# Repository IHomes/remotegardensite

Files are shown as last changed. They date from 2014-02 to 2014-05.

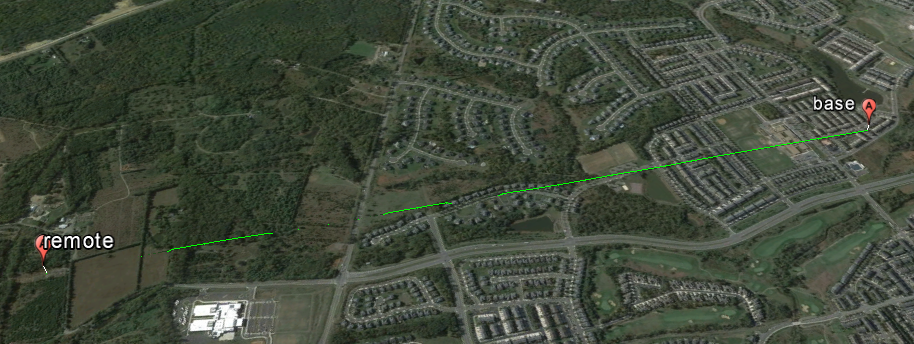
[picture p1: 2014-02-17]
rf_modeling/splat/example_misc_summary_files/Base_to_Remote_LineofSight.png

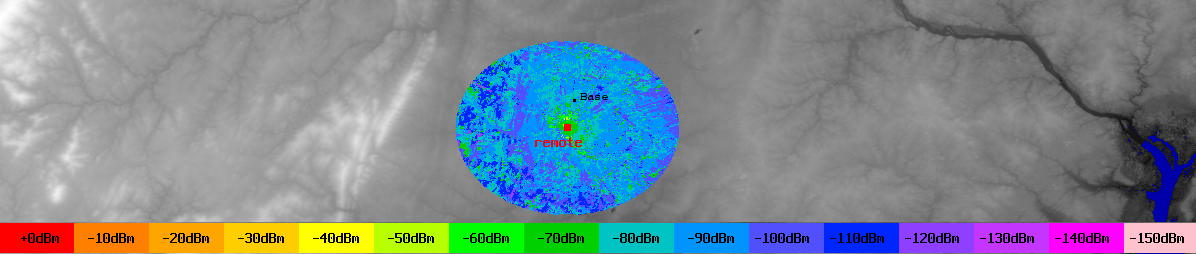
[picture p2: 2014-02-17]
rf_modeling/splat/example_misc_summary_files/Remote_xdBGain_coverage_dBm.png

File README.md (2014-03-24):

# Overview

A garden monitor/weather station hosted on a Raspberry Pi. This projects goal is to monitor the remote weather station over a great distance (miles,) and post the data online.

RPi Setup Reference:
RPi_remote_garden_monitor_prep_ArchLinux.txt

RPi900 Setup Reference:
rpi900_dnt900_setup_with_ppp.txt (Summary steps, see http://rpi900.com/ for full details)

##garden_monitor
Scripts to gather weather or hardware health data and post to xively

## public_html
Example html for displaying data.
-Historical displays powered by https://github.com/jasonneylon/xively-rickshaw

## sensors
Sensors and supporting scripts used in the remote garden monitor

##transeiver_dnt900
Data concerning a long distance communication transeiver utilized in this project

##rf_modeling
Sample data from RF communication modeling done for the base/remote setup.

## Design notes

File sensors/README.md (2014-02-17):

# Sensors used in the projects
-Air Temp Sensor (DS1820)
-Ground Temp Sensor (SHT10)
-Soil Moisture Sensor (SHT10)
-Pi Onboard CPU Temp (onboard/vcgencmd)
-Pi Camera (camera/raspistill)

## DS18B20
An i2c Digital temperature sensor (I happened to use adafruit Waterproof DS18B20 Digital temperature sensor + extras) for this project.

Each has a unique address, found with steps below. Script would need updating if you have more than of this type of sensor, reflecting the specific serial number perhaps

```
sudo modprobe w1-gpio
sudo modprobe w1-therm
cd /sys/bus/w1/devices
ls
cd 28-* #unique serial number for device, if you add multiple make sure to keep track of them
cat w1_slave  #indicates if temp can be provided in first line, temp in second.
```

Python script in this repo (thermometer.py) from this tutorial: 
http://learn.adafruit.com/adafruits-raspberry-pi-lesson-11-ds18b20-temperature-sensing

To run program:
```
cd DS18B20
python thermometer.py
```

## SH10
An i2c Soil/Moisture (humidity) sensor (again, I happened to use adafruit offering)

No-unique address, multiple *may* be possible with unique data lines

Followed this exactly:
http://www.john.geek.nz/2012/08/reading-data-from-a-sensirion-sht1x-with-a-raspberry-pi/

Requires BCM2835 library (included as-used in this repo, but latest: http://www.open.com.au/mikem/bcm2835 )

If used version of BCM2835 from this repo:

```
cd ./SHT10/support_files/bcm2835-1.36
./configure
make
sudo make check
sudo make install
```

To build program 

```
cd ../.. #SHT10
gcc -o RPi_SHT1x ./support_files/bcm2835-1.36/src/bcm2835.c ./RPi_SHT1x.c testSHT1x.c
```

To run program:

```
cd SHT10
./RPi_SHT1x
```
## Raspberry Pi Onboard Sensors

Ref: http://elinux.org/RPI_vcgencmd_usage

To list CPU core temp:

```
/opt/vc/bin/vcgencmd measure_temp
# or
gawk '{print $1/1000,"degrees C"}' /sys/class/thermal/thermal_zone0/temp
```

## Pi Camera

Script to grab an image every 30 seconds, Ref: http://www.stuffaboutcode.com/2013/05/time-lapse-video-with-raspberry-pi.html

```
cd camera
capturetimelapse_30secInt.sh
```

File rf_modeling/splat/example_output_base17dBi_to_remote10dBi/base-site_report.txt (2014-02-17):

	--==[ SPLAT! v1.4.1 Site Analysis Report For: base ]==--

---------------------------------------------------------------------------

Site location: XXX
Ground elevation: 275.59 feet AMSL
Antenna height: 40.00 feet AGL / 315.59 feet AMSL
Antenna height above average terrain: -31.86 feet

Average terrain at   0 degrees azimuth: 347.86 feet AMSL
Average terrain at  45 degrees azimuth: 295.19 feet AMSL
Average terrain at  90 degrees azimuth: 347.88 feet AMSL
Average terrain at 135 degrees azimuth: 309.48 feet AMSL
Average terrain at 180 degrees azimuth: 243.13 feet AMSL
Average terrain at 225 degrees azimuth: 340.09 feet AMSL
Average terrain at 270 degrees azimuth: 534.30 feet AMSL
Average terrain at 315 degrees azimuth: 361.65 feet AMSL

---------------------------------------------------------------------------

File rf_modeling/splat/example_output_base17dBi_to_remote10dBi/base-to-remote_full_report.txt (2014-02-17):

		--==[ SPLAT! v1.4.1 Path Analysis ]==--

---------------------------------------------------------------------------

Transmitter site: base
Site location: XXX
Ground elevation: 275.59 feet AMSL
Antenna height: 40.00 feet AGL / 315.59 feet AMSL
Antenna height above average terrain: -31.86 feet
Distance to remote  : 1.64 miles
Azimuth to remote  : 191.56 degrees
Elevation angle to remote  : +0.1255 degrees
Elevation angle to the first obstruction: +0.1678 degrees

---------------------------------------------------------------------------

Receiver site: remote  
Site location: XXX
Ground elevation: 331.36 feet AMSL
Antenna height: 5.00 feet AGL / 336.36 feet AMSL
Antenna height above average terrain: -17.03 feet
Distance to base: 1.64 miles
Azimuth to base: 11.56 degrees
Depression angle to base: -0.1493 degrees
Depression angle to the first obstruction: -0.0837 degrees

---------------------------------------------------------------------------

ITWOM Version 3.0 Parameters Used In This Analysis:

Earth's Dielectric Constant: 15.000
Earth's Conductivity: 0.005 Siemens/meter
Atmospheric Bending Constant (N-units): 301.000 ppm
Frequency: 915.000 MHz
Radio Climate: 5 (Continental Temperate)
Polarization: 0 (Horizontal)
Fraction of Situations: 50.0%
Fraction of Time: 90.0%
Transmitter ERP: 31 Watts (+44.85 dBm)
Transmitter EIRP: 50 Watts (+46.99 dBm)

---------------------------------------------------------------------------

Summary For The Link Between base and remote  :

Free space path loss: 100.13 dB
ITWOM Version 3.0 path loss: 109.52 dB
Attenuation due to terrain shielding: 9.39 dB
Field strength at remote  : 73.96 dBuV/meter
Signal power level at remote  : -62.53 dBm
Signal power density at remote  : -71.82 dBW per square meter
Voltage across a 50 ohm dipole at remote  : 213.88 uV (46.60 dBuV)
Voltage across a 75 ohm dipole at remote  : 261.95 uV (48.36 dBuV)
Mode of propagation: Single Horizon Diffraction Dominant
ITWOM error number: 0 (No error)

---------------------------------------------------------------------------

Between remote   and base, SPLAT! detected obstructions at:

    XXX  0.22 miles, 334.65 feet AMSL
    XXX  0.28 miles, 337.93 feet AMSL

Antenna at remote   must be raised to at least 12.00 feet AGL
to clear all obstructions detected by SPLAT!.

Antenna at remote   must be raised to at least 91.00 feet AGL
to clear the first Fresnel zone.

Antenna at remote   must be raised to at least 51.00 feet AGL
to clear 60% of the first Fresnel zone.

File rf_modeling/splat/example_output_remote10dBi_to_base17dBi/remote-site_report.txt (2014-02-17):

	--==[ SPLAT! v1.4.1 Site Analysis Report For: remote   ]==--

---------------------------------------------------------------------------

Site location: XXX
Ground elevation: 331.36 feet AMSL
Antenna height: 5.00 feet AGL / 336.36 feet AMSL

---------------------------------------------------------------------------

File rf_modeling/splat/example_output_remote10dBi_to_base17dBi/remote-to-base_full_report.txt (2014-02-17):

		--==[ SPLAT! v1.4.1 Path Analysis ]==--

---------------------------------------------------------------------------

Transmitter site: remote  
Site location: XXX
Ground elevation: 331.36 feet AMSL
Antenna height: 5.00 feet AGL / 336.36 feet AMSL
Distance to base: 1.64 miles
Azimuth to base: 11.56 degrees
Depression angle to base: -0.1493 degrees
Depression angle to the first obstruction: -0.0837 degrees

---------------------------------------------------------------------------

Receiver site: base
Site location: XXX
Ground elevation: 275.59 feet AMSL
Antenna height: 40.00 feet AGL / 315.59 feet AMSL
Distance to remote  : 1.64 miles
Azimuth to remote  : 191.56 degrees
Elevation angle to remote  : +0.1255 degrees
Elevation angle to the first obstruction: +0.1678 degrees

---------------------------------------------------------------------------

ITWOM Version 3.0 Parameters Used In This Analysis:

Earth's Dielectric Constant: 15.000
Earth's Conductivity: 0.005 Siemens/meter
Atmospheric Bending Constant (N-units): 301.000 ppm
Frequency: 915.000 MHz
Radio Climate: 5 (Continental Temperate)
Polarization: 0 (Horizontal)
Fraction of Situations: 50.0%
Fraction of Time: 90.0%
Transmitter ERP: 6.1 Watts (+37.85 dBm)
Transmitter EIRP: 10.0 Watts (+39.99 dBm)

---------------------------------------------------------------------------

Summary For The Link Between remote   and base:

Free space path loss: 100.13 dB
ITWOM Version 3.0 path loss: 106.78 dB
Attenuation due to terrain shielding: 6.64 dB
Field strength at base: 69.70 dBuV/meter
Signal power level at base: -66.78 dBm
Signal power density at base: -76.08 dBW per square meter
Voltage across a 50 ohm dipole at base: 131.01 uV (42.35 dBuV)
Voltage across a 75 ohm dipole at base: 160.46 uV (44.11 dBuV)
Mode of propagation: Single Horizon Diffraction Dominant
ITWOM error number: 0 (No error)

---------------------------------------------------------------------------

Between base and remote  , SPLAT! detected obstructions at:

    XXX  1.36 miles, 337.93 feet AMSL

Antenna at base must be raised to at least 72.00 feet AGL
to clear all obstructions detected by SPLAT!.

Antenna at base must be raised to at least 291.00 feet AGL
to clear the first Fresnel zone.

Antenna at base must be raised to at least 198.00 feet AGL
to clear 60% of the first Fresnel zone.

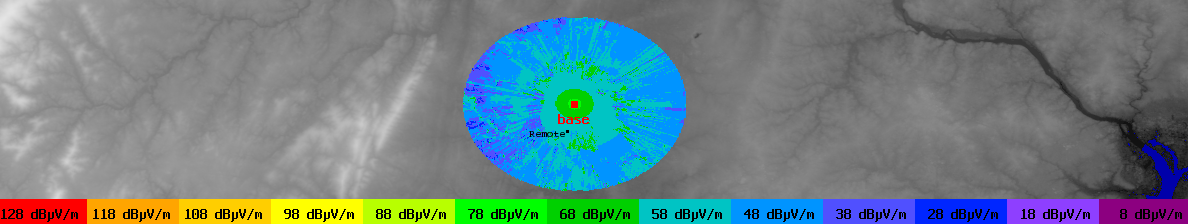
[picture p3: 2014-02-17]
rf_modeling/splat/example_misc_summary_files/Base_xxdBGain_coverage_fieldStrength.png

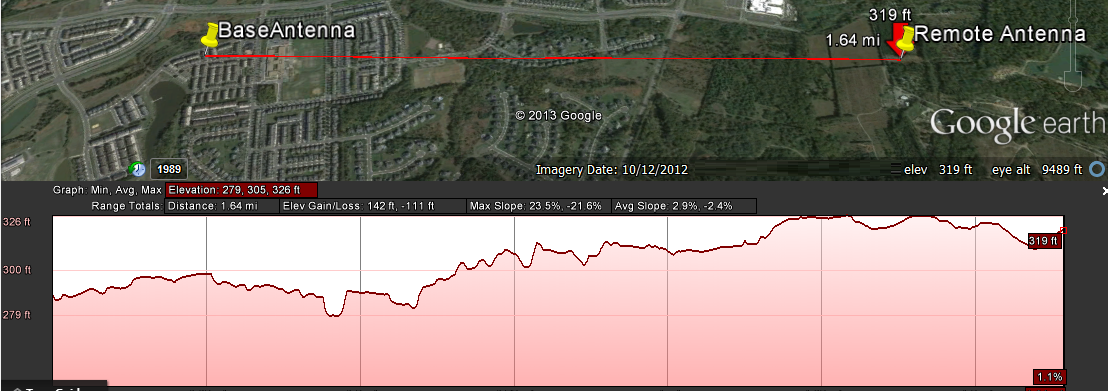
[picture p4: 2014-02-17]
rf_modeling/splat/example_misc_summary_files/ground_elevation_profile.png

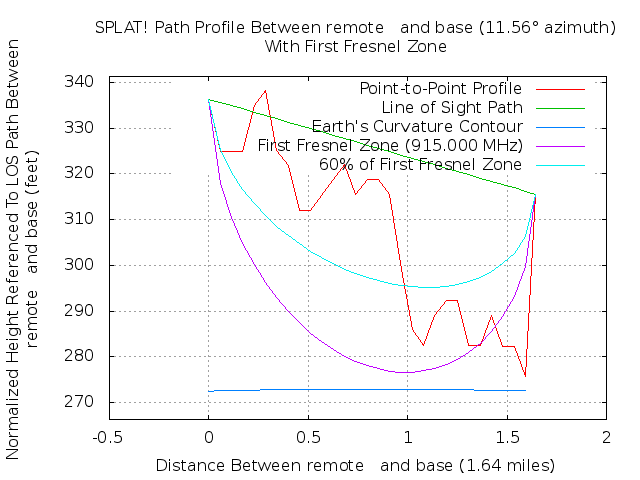
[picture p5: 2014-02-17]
rf_modeling/splat/example_output_base17dBi_to_remote10dBi/normalizedterrianHeight.png

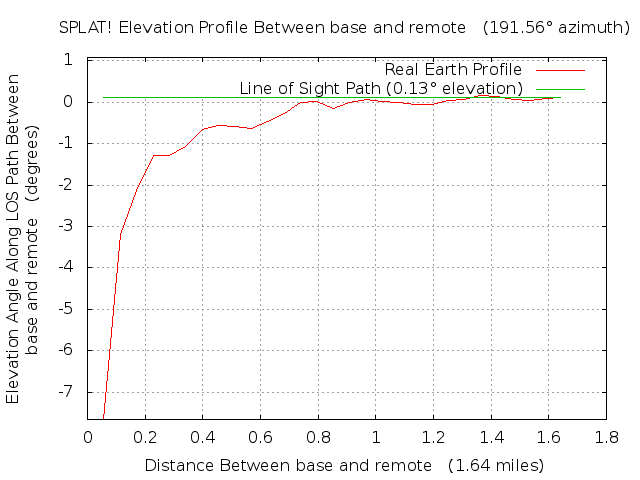
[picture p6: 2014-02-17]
rf_modeling/splat/example_output_remote10dBi_to_base17dBi/elavation.png

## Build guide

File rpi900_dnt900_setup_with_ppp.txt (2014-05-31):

# Manual steps for setting up rpi900/dnt900 with ppp
#
# All derived from an older version of tutorials on rpi900.com
# ----------http://rpi900.com/tutorials/rpi900-packages.html 
# ------------ has since published packages to make this much
# ---------------easier
#
#

#---------------------------------------------
# rpi900/dnt900/dnt2400 setup 
#---------------------------------------------

This is somewhat specific to a particular base/remote setup; http://rpi900.com/ is the source for all this information and a much better reference than this document.

#---------------------------------------------
# setup groups/permissions
#---------------------------------------------
groupadd dnt900
usermod -a -G dnt900 root
echo 'KERNEL=="ttyAMA0" GROUP="dnt900"' > /etc/udev/rules.d/99-ttyAMA0.rules
udevadm trigger --sysname-match=ttyAMA0

#---------------------------------------------
# disable serial console
#---------------------------------------------
cat /boot/cmdline.txt
sed -i.old 's/[^ ]*ttyAMA0[^ ]*//g' /boot/cmdline.txt
cat /boot/cmdline.txt
systemctl disable serial-getty@ttyAMA0.service

#---------------------------------------------
# flow control
#---------------------------------------------

cd
git clone git://github.com/mholling/rpirtscts.git
cd rpirtscts
make
cp rpirtscts /usr/local/bin/
rpirtscts on
stty -F /dev/ttyAMA0 crtscts

#---------------------------------------------
# dnt900 line discipline //typically just base, but used on remote sometimes
#---------------------------------------------

cd 
git clone https://github.com/mholling/dnt900.git
make
make modules_install 
depmod -a

chmod 777 /dev/ttyAMA0
echo dnt900 > /etc/modules-load.d/dnt900.conf

cp ./systemd_files/dnt900.service /etc/systemd/system/dnt900.service

#had a note to do this at this point
reboot

cp ./udev_rules 99-dnt900.rules_base /etc/udev/rules.d/99-dnt900.rules
# if on remote
# cp ./udev_rules 99-dnt900.rules_remote /etc/udev/rules.d/99-dnt900.rules

#if running on remote, make sure to stop ppp service
systemctl enable dnt900.service
systemctl start dnt900.service

#---------------------------------------------
# setting up ppp on remote
#---------------------------------------------

hostnamectl set-hostname remotepi

cp ./ppp/base /etc/ppp/peers/

systemctl enable ppp@base.service

cp ./ppp/pap-secrets_remote /etc/ppp/pap-secrets

#---------------------------------------------
# setting up ppp on base
#---------------------------------------------

hostnamectl set-hostname basepi

cp ./ppp/remote /etc/ppp/peers/

cp ./systemd_files/ppp-remote@.service /etc/systemd/system/

cp ./ppp/pap-secrets_base /etc/ppp/pap-secrets

echo 'net.ipv4.conf.eth0.proxy_arp = 1' >> /etc/sysctl.d/99-sysctl.conf
echo 'net.ipv4.ip_forward = 1' >> /etc/sysctl.d/99-sysctl.conf

#---------------------------------------------
# DNS resolution
#---------------------------------------------

echo >> /etc/resolvconf.conf
echo name_servers=8.8.8.8 >> /etc/resolvconf.conf
resolvconf -u

#---------------------------------------------
# Not sure required, maybe done during troubleshooting
# noticed out of date already (gets out of date on pacman update)
#---------------------------------------------

cd /usr/src
ln -s linux-3.10.25-1-ARCH linux #or whatever latest
cd /lib/modules/3.10.25-1-ARCH/
ln -s /usr/src/linux build

#---------------------------------------------
# Did not end up using...
# Setting Static (ethernet-static file would need to be configured)
#---------------------------------------------

cd /etc/netctl

file currently has:
Interface=eth0
Connection=ethernet
IP=static
Address='192.168.1.157/24'
#Routes=('192.168.0.0/24 via 192.168.1.2')
#Gateway=:'192.168.100.1'
DNS='8.8.8.8'
AutoWired=yes

netctl enable ethernet-static
systemctl disable dhcpcd@eth0.service

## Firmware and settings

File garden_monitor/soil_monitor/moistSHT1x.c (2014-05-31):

// Compile with: gcc -o moistSHT1x ./support_files/bcm2835-1.36/src/bcm2835.c ./RPi_SHT1x.c moistSHT1x.c

/*
Raspberry Pi SHT1x communication library.
By:      John Burns (www.john.geek.nz)
Date:    01 November 2012
License: CC BY-SA v3.0 - http://creativecommons.org/licenses/by-sa/3.0/

This is a derivative work based on
	Name: Nice Guy SHT11 library
	By: Daesung Kim
	Date: 04/04/2011
	Source: http://www.theniceguy.net/2722
	License: Unknown - Attempts have been made to contact the author

Dependencies:
	BCM2835 Raspberry Pi GPIO Library - http://www.open.com.au/mikem/bcm2835/

Sensor:
	Sensirion SHT10 Temperature and Humidity Sensor interfaced to Raspberry Pi GPIO port

SHT pins:
	1. GND  - Connected to GPIO Port P1-06 (Ground)
	2. DATA - Connected via a 10k pullup resistor to GPIO Port P1-01 (3V3 Power)
	2. DATA - Connected to GPIO Port P1-18 (GPIO 24)
	3. SCK  - Connected to GPIO Port P1-16 (GPIO 23)
	4. VDD  - Connected to GPIO Port P1-01 (3V3 Power)

Note:
	GPIO Pins can be changed in the Defines of RPi_SHT1x.h
*/

#include <bcm2835.h>
#include <stdio.h>
#include "RPi_SHT1x.h"

void printTempAndHumidity(void)
{
	unsigned char noError = 1;  
	value humi_val,temp_val;
	
	
	// Wait at least 11ms after power-up (chapter 3.1)
	delay(20); 
	
	// Set up the SHT1x Data and Clock Pins
	SHT1x_InitPins();
	
	// Reset the SHT1x
	SHT1x_Reset();
	
	// Request Temperature measurement
	noError = SHT1x_Measure_Start( SHT1xMeaT );
	if (!noError) {
		return;
		}
		
	// Read Temperature measurement
	noError = SHT1x_Get_Measure_Value( (unsigned short int*) &temp_val.i );
	if (!noError) {
		return;
		}

	// Request Humidity Measurement
	noError = SHT1x_Measure_Start( SHT1xMeaRh );
	if (!noError) {
		return;
		}
		
	// Read Humidity measurement
	noError = SHT1x_Get_Measure_Value( (unsigned short int*) &humi_val.i );
	if (!noError) {
		return;
		}

	// Convert intergers to float and calculate true values
	temp_val.f = (float)temp_val.i;
	humi_val.f = (float)humi_val.i;
	
	// Calculate Temperature and Humidity
	SHT1x_Calc(&humi_val.f, &temp_val.f);

	//Print the Temperature to the console
	//printf("Temperature: %0.2f%cC\n",temp_val.f,0x00B0);

	//Print the Humidity to the console
	//printf("Humidity: %0.2f%%\n",humi_val.f);
	//Calculate and print the Dew Point
	float fDewPoint;
	SHT1x_CalcDewpoint(humi_val.f ,temp_val.f, &fDewPoint);
	//printf("Dewpoint: %0.2f%cC\n",fDewPoint,0x00B0);

FILE *file;
file = fopen("lastread_soil_moist.out","w");
fprintf(file,"%0.2f\n",humi_val.f);
fclose(file);
}

int main ()
{
	//Initialise the Raspberry Pi GPIO
	if(!bcm2835_init())
		return 1;
	
	printTempAndHumidity();

	return 1;
}

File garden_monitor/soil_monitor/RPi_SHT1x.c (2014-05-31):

/*
Raspberry Pi SHT1x communication library.
By:      John Burns (www.john.geek.nz)
Date:    01 November 2012
License: CC BY-SA v3.0 - http://creativecommons.org/licenses/by-sa/3.0/

This is a derivative work based on
	Name: Nice Guy SHT11 library
	By: Daesung Kim
	Date: 04/04/2011
	Source: http://www.theniceguy.net/2722
	License: Unknown - Attempts have been made to contact the author
*/

#include "RPi_SHT1x.h"

/* Global variables of the SHT1x sensor */
unsigned char SHT1x_crc;
unsigned char SHT1x_status_reg = 0;

void SHT1x_Crc_Check(unsigned char value) 
{
	unsigned char i;

	for (i=8; i; i--)
	{
		if ((SHT1x_crc ^ value) & 0x80)
		{
			SHT1x_crc <<= 1;
			SHT1x_crc ^= 0x31;
		}
		else
		{
			SHT1x_crc <<= 1;
		}
		value <<=1;
	}
}

void SHT1x_InitPins( void ) 
{
	// SCK line as output but set to low first
		bcm2835_gpio_write(RPI_GPIO_SHT1x_SCK, LOW);
		bcm2835_gpio_fsel(RPI_GPIO_SHT1x_SCK, BCM2835_GPIO_FSEL_OUTP);
	bcm2835_gpio_write(RPI_GPIO_SHT1x_SCK, LOW);

	// DATA to input. External pull up.
	// Set PORT to 0 => pull data line low by setting port as output
		bcm2835_gpio_set_pud(RPI_GPIO_SHT1x_DATA, BCM2835_GPIO_PUD_OFF);
	bcm2835_gpio_write(RPI_GPIO_SHT1x_DATA,LOW);
		bcm2835_gpio_fsel(RPI_GPIO_SHT1x_DATA, BCM2835_GPIO_FSEL_OUTP);
	bcm2835_gpio_set_pud(RPI_GPIO_SHT1x_DATA, BCM2835_GPIO_PUD_OFF);
		bcm2835_gpio_write(RPI_GPIO_SHT1x_DATA,LOW);
}

void SHT1x_Reset() 
{
	// Chapter 3.4
	unsigned char i;
	SHT1x_DATA_HI;
	SHT1x_DELAY;
	for (i=9; i; i--)
	{
		SHT1x_SCK_HI;	SHT1x_DELAY;
		SHT1x_SCK_LO;	SHT1x_DELAY;
	}
	SHT1x_Transmission_Start();
	SHT1x_Sendbyte(SHT1x_RESET);  // Soft reset
}

void SHT1x_Transmission_Start( void ) 
{
	// Chapter 3.2
	SHT1x_SCK_HI;	SHT1x_DELAY;
	SHT1x_DATA_LO;	SHT1x_DELAY;
	SHT1x_SCK_LO;	SHT1x_DELAY;
	SHT1x_SCK_HI;	SHT1x_DELAY;
	SHT1x_DATA_HI;	SHT1x_DELAY;
	SHT1x_SCK_LO;	SHT1x_DELAY;
	
	// Reset crc calculation. Start value is the content of the status register.
	SHT1x_crc = SHT1x_Mirrorbyte( SHT1x_status_reg & 0x0F );
}

unsigned char SHT1x_Mirrorbyte(unsigned char value) 
{
	unsigned char ret=0, i;

	for (i=0x80; i ; i>>=1)
	{
		if(value & 0x01)
			ret |= i;

		value >>= 1;
	}

	return ret;
}

unsigned char SHT1x_Readbyte( unsigned char send_ack ) 
{
	unsigned char mask;
	unsigned char value = 0;

	// SCK is low here !
	for(mask=0x80; mask; mask >>= 1 )
	{
		SHT1x_SCK_HI;	SHT1x_DELAY;  	// SCK hi
		if( SHT1x_GET_BIT != 0 )  	// and read data
			value |= mask;

		SHT1x_SCK_LO;	SHT1x_DELAY; // SCK lo => sensor puts new data
	}

	/* send ACK if required */
	if ( send_ack )
	{
		SHT1x_DATA_LO;	SHT1x_DELAY; // Get DATA line
	}
	
	SHT1x_SCK_HI;	SHT1x_DELAY;    // give a clock pulse
	SHT1x_SCK_LO;	SHT1x_DELAY; 
	
	if ( send_ack )
	{       // Release DATA line
		SHT1x_DATA_HI;	SHT1x_DELAY; 
	}

	return value;
}

unsigned char SHT1x_Sendbyte( unsigned char value ) 
{
	unsigned char mask;
	unsigned char ack;

	for(mask = 0x80; mask; mask>>=1)
	{
		SHT1x_SCK_LO;	SHT1x_DELAY;

		if( value & mask )
		{  
			SHT1x_DATA_HI; 	SHT1x_DELAY;
		}
		else
		{
			SHT1x_DATA_LO;	SHT1x_DELAY;
		}

		SHT1x_SCK_HI;	SHT1x_DELAY;  // SCK hi => sensor reads data
	}
	SHT1x_SCK_LO;	SHT1x_DELAY;

	// Release DATA line
	SHT1x_DATA_HI;	SHT1x_DELAY;
	SHT1x_SCK_HI;	SHT1x_DELAY;

	ack = 0;

	if(!SHT1x_GET_BIT)
		ack = 1;

	SHT1x_SCK_LO;	SHT1x_DELAY;

	SHT1x_Crc_Check(value);   // crc calculation

	return ack;
}

unsigned char SHT1x_Measure_Start( SHT1xMeasureType type ) 
{
	// send a transmission start and reset crc calculation
	SHT1x_Transmission_Start();
	// send command. Crc gets updated!
	return SHT1x_Sendbyte( (unsigned char) type );
}

unsigned char SHT1x_Get_Measure_Value( unsigned short int * value ) 
{
	unsigned char * chPtr = (unsigned char*) value;
	unsigned char checksum;
	unsigned char delay_count=62;  /* delay is 62 * 5ms */

	/* Wait for measurement to complete (DATA pin gets LOW) */
	/* Raise an error after we waited 250ms without success (210ms + 15%) */
	while( SHT1x_GET_BIT )
	{
		delayMicroseconds(5000);			// $$$$$$$$$$$$$$$$$$ 1 ms not working $$$$$$$$$$$$$$$$$$$$$$$$
	
		delay_count--;
		if (delay_count == 0)
			return FALSE;
	}

	*(chPtr + 1) = SHT1x_Readbyte( TRUE );  // read hi byte
	SHT1x_Crc_Check(*(chPtr + 1));  		// crc calculation
	*chPtr = SHT1x_Readbyte( TRUE );    	// read lo byte
	SHT1x_Crc_Check(* chPtr);    			// crc calculation

	checksum = SHT1x_Readbyte( FALSE );   // crc calculation
	// compare it.
	return SHT1x_Mirrorbyte( checksum ) == SHT1x_crc ? TRUE : FALSE;
}



//----------------------------------------------------------------------------------------
void SHT1x_Calc(float *p_humidity ,float *p_temperature)
//----------------------------------------------------------------------------------------
{
	const float C1=-2.0468;            		// for 12 Bit
	const float C2=+0.0367;           		// for 12 Bit
	const float C3=-0.0000015955;      		// for 12 Bit
	const float T1=+0.01;             		// for 12 Bit
	const float T2=+0.00008;           		// for 12 Bit

	const float	D1 = -39.66;			// For 3.3 Volt power supply, Centigrade
	const float	D2 = 0.01;			// For 14 Bit temperature, Centigrade

	float rh = *p_humidity;             		// rh:      Humidity [Ticks] 12 Bit 
	float t = *p_temperature;          		// t:       Temperature [Ticks] 14 Bit
	float rh_lin;                     		// rh_lin:  Humidity linear
	float rh_true;                    		// rh_true: Temperature compensated humidity
	float t_C;                        		// t_C   :  Temperature [C]

	t_C = D1 + (D2 * t);                  		// calc. temperature from ticks to [C]
	rh_lin = C1 + (C2 * rh) + (C3 * rh * rh);	// calc. humidity from ticks to [%RH]
	rh_true = (t_C - 25) *(T1 + (T2 * rh)) + rh_lin;// calc. temperature compensated humidity [%RH]
	if(rh_true>100) rh_true=100;       		// cut if the value is outside of
	if(rh_true<0.1)	rh_true=0.1;       		// the physical possible range
        t_C = t_C*9/5 + 32;                             // hacking in Farenheit
	*p_temperature = t_C;               		// return temperature [C]
	*p_humidity = rh_true;              		// return humidity[%RH]
}

//----------------------------------------------------------------------------------------
void SHT1x_CalcDewpoint(float fRH ,float fTemp, float *fDP)
//----------------------------------------------------------------------------------------
// Calculates Dewpoint based on Page 9 (v5, Dec 2011) of SHT1x Datasheet
{
	// Set some constants for the temperature range
	float Tn = 243.12;
	float m = 17.62;
	if (fTemp < 0)
	{
		Tn = 272.62;
		m = 22.46;
	}
	//not using this, but original code was float lnRH = log(fRH/100); but would not compile
        float lnRH = 2*(fRH/100);
	float mTTnT = (m * fTemp)/(Tn+fTemp);
	
	*fDP = Tn * ((lnRH + mTTnT)/(m - lnRH - mTTnT));
}

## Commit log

2014-02-17 minor update and supporting files including sensor tools
2014-03-05 removing unneeded print statements and general cleanup
2014-03-05 fritzing of initial protoboard
    [fritzing_protoboard.fzz]
2014-03-10 aesthetic adjustments to protoboard
    [fritzing_protoboard.fzz]
2014-05-31 updated SHT10 temp/moist source
    Updates per
    http://www.john.geek.nz/2012/11/update-reading-data-from-a-sensirion-sht1x-with-a-raspberry-pi/
2014-05-31 scripts as currently being run at garden
    battery saving values
